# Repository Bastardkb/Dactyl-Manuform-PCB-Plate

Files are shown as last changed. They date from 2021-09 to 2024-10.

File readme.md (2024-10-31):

# Dactyl Manuform Mini PCB - plate

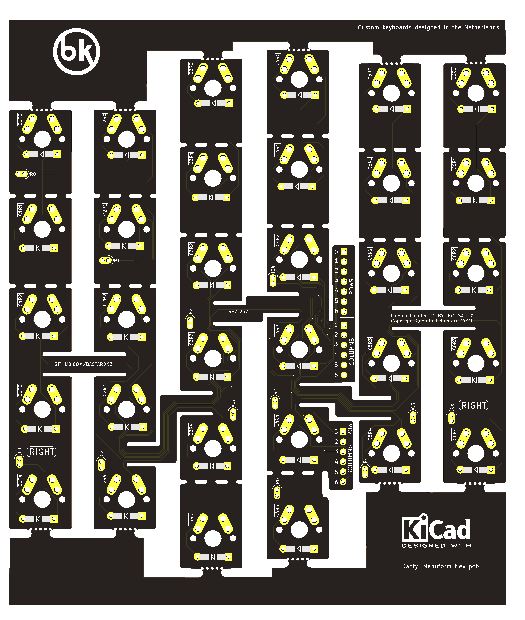
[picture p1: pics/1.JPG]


Flexible PCB made for the Dactyl Manuform Mini - up to 6x6 and breakable down to 5x3.

This repository contains all files necessary to order a PCB.

If you want to modify the design files, the Kicad sources are included (you will need a 5.99 nightly version).
If you just want to order the PCBs, check out the Release section which contain the gerber files.

## How to order

Order with a 0.6mm PCB thickness

## License

Licensed under CC BY-NC-SA 4.0
Copyright Quentin Lebastard 2021

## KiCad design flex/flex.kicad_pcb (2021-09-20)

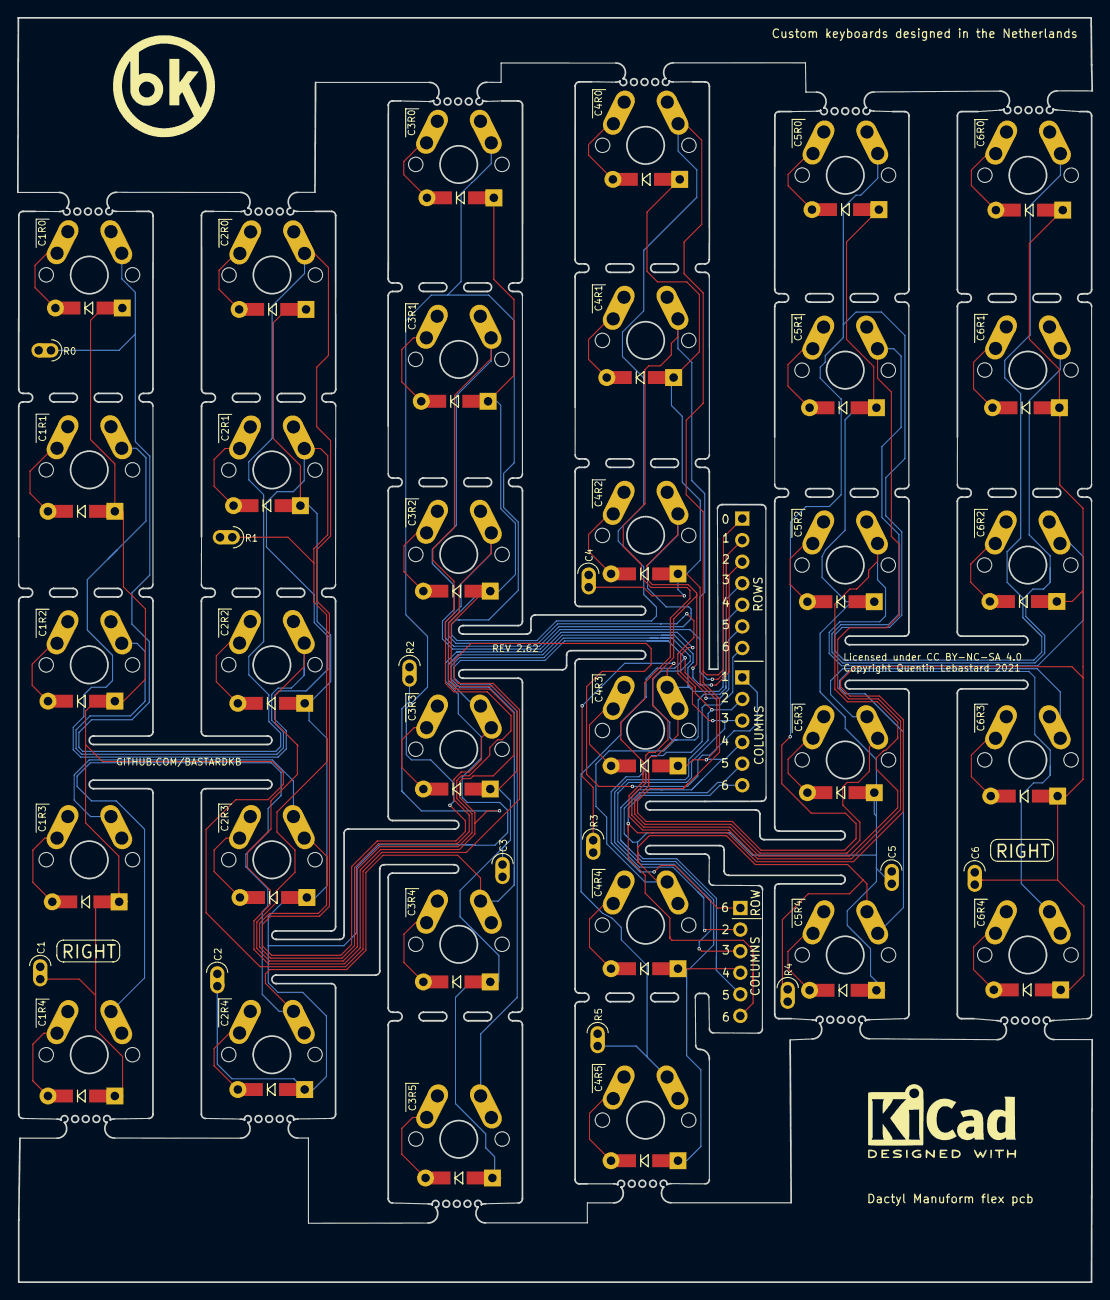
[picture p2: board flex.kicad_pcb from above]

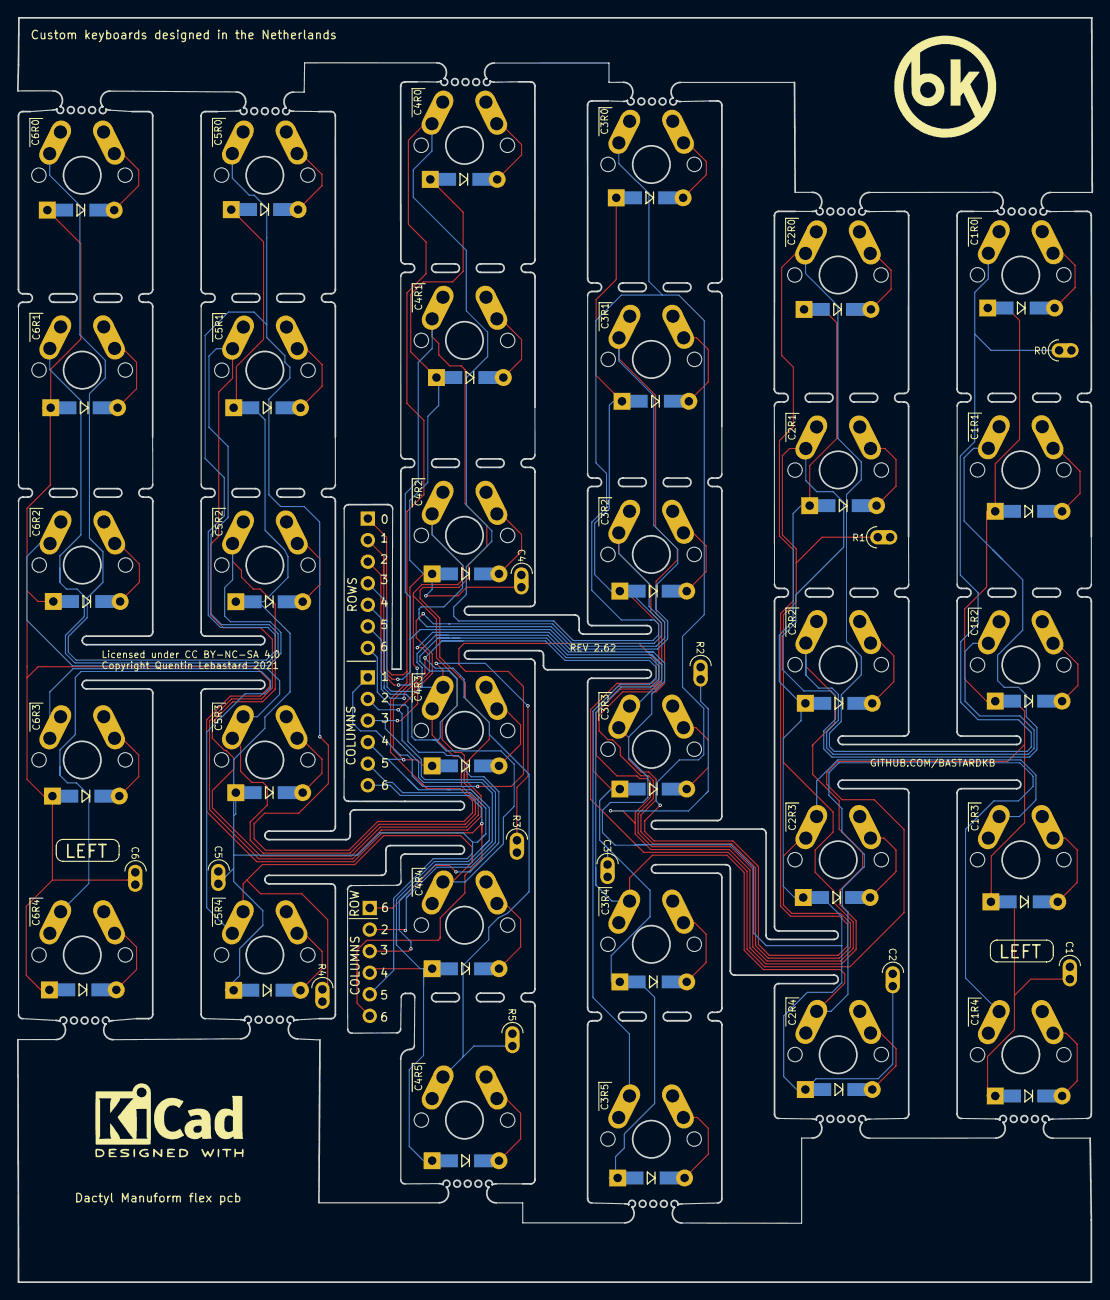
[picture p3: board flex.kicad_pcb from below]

Board: 2 copper layers, 126.5 x 148.9 mm, 79 parts (58 on the bottom side), 45 nets.

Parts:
D1, D2, D3, D4, D5, D6, D7, D8, D9, D10, D11, D12, D13, D14, D15, D16, D17, D18, D19, D20, D21, D22, D23, D24, D25, D26, D27, D28, D29, D30, D31, D32: D; Diode_TH_SOD123
J1, J14: Conn_01x06_Female; PinSocket_1x06_P2.54mm_Vertical
J2: Conn_01x07_Female; PinSocket_1x07_P2.54mm_Vertical
J3, J4, J5, J6, J7, J8, J9, J10, J11, J12, J13, J15: Conn_01x02_Female; SolderWire-0.15sqmm_1x01_D0.5mm_OD1.5mm
SW1, SW2, SW3, SW4, SW5, SW6, SW7, SW8, SW9, SW10, SW11, SW12, SW13, SW14, SW15, SW16, SW17, SW18, SW19, SW20, SW21, SW22, SW23, SW24, SW25, SW26, SW27, SW28, SW29, SW30, SW31, SW32: SW_Push; SW_MX_reversible

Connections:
unnamed: D1.2 (A), SW1.2
unnamed: D2.2 (A), SW2.2
unnamed: D3.2 (A), SW3.2
unnamed: D4.2 (A), SW4.2
unnamed: D5.2 (A), SW5.2
unnamed: D6.2 (A), SW6.2
unnamed: D7.2 (A), SW7.2
unnamed: D8.2 (A), SW8.2
unnamed: D9.2 (A), SW9.2
unnamed: D10.2 (A), SW10.2
unnamed: D11.2 (A), SW11.2
unnamed: D12.2 (A), SW12.2
unnamed: D13.2 (A), SW13.2
unnamed: D14.2 (A), SW14.2
unnamed: D15.2 (A), SW15.2
unnamed: D16.2 (A), SW16.2
unnamed: D17.2 (A), SW17.2
unnamed: D18.2 (A), SW18.2
unnamed: D19.2 (A), SW19.2
unnamed: D20.2 (A), SW20.2
unnamed: D21.2 (A), SW21.2
unnamed: D22.2 (A), SW22.2
unnamed: D23.2 (A), SW23.2
unnamed: D24.2 (A), SW24.2
unnamed: D25.2 (A), SW25.2
unnamed: D26.2 (A), SW26.2
unnamed: D27.2 (A), SW27.2
unnamed: D28.2 (A), SW28.2
unnamed: D29.2 (A), SW29.2
unnamed: D30.2 (A), SW30.2
unnamed: D31.2 (A), SW31.2
unnamed: D32.2 (A), SW32.2
col1: D1.1 (K), D2.1 (K), D3.1 (K), D4.1 (K), D27.1 (K), J9.1, J14.1
col2: D5.1 (K), D6.1 (K), D7.1 (K), D8.1 (K), D28.1 (K), J1.2, J10.1, J14.2
col3: D9.1 (K), D10.1 (K), D11.1 (K), D12.1 (K), D13.1 (K), D29.1 (K), J1.3, J11.1, J14.3
col4: D14.1 (K), D15.1 (K), D16.1 (K), D17.1 (K), D18.1 (K), D30.1 (K), J1.4, J12.1, J14.4
col5: D19.1 (K), D20.1 (K), D21.1 (K), D22.1 (K), D31.1 (K), J1.5, J13.1, J14.5
col6: D23.1 (K), D24.1 (K), D25.1 (K), D26.1 (K), D32.1 (K), J1.6, J14.6, J15.1
row0: J2.1, J3.1, SW27.1, SW28.1, SW29.1, SW30.1, SW31.1, SW32.1
row1: J2.2, J4.1, SW1.1, SW5.1, SW9.1, SW14.1, SW19.1, SW23.1
row2: J2.3, J5.1, SW2.1, SW6.1, SW10.1, SW15.1, SW20.1, SW24.1
row3: J2.4, J6.1, SW3.1, SW7.1, SW11.1, SW16.1, SW21.1, SW25.1
row4: J2.5, J7.1, SW4.1, SW8.1, SW12.1, SW17.1, SW22.1, SW26.1
row5: J2.6, J8.1, SW13.1, SW18.1
row6: J1.1, J2.7

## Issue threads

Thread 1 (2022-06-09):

What vendor have you used to manufacture this PCB?

efenderbosch, 2022-06-09:
I'm trying JLCPCB and they are having all sorts of issues understanding the gerber files. I've separated them in to two separate zips, flex_B and flex_F, but I think the fact that one is mirrored is really confusing them. Should I try to use Kicad to "unmirror" those? Thanks.

bstiq, 2022-06-09:
Hi,

We and others ordered them with JLC, so they can definetly manufacture them.
The B and F stand for Back and Front layers.

Did you grab the gerber from the release section ? Do you have maybe screenshots of the conversation with JLC ?

efenderbosch, 2022-06-09:
I did grab them from the release section. I created 2 zip from the contents:
- flex-B_*.gbr + flex-Edge_Cuts.gbr + flex-PTH.drl
- flex-H_*.gbr + flex-Edge_Cuts.gbr + flex-PTH.drl

Email conversation:
>Hi Sir or madam,
 Well got your order with many thanks~
 Sorry to bother you, but there is an issue that we want to confirm with you before proceeding.
 There is no bottom solder mask layer, is that normal? If it is normal, there are 2 option for reference. There is no bare copper available.（if it is wrong, we will help you activate the replace file button that you can fix and reupload）.
 A : We cover it all with tin.—(can solder things)
 B: we cover it all with solder mask ink.—(can’t solder anything)
 Your early reply will be highly appreciated!
 Thank you so much!

My reply:
> The zip files both have a mask.gbr, so I'm a little confused. One is designed to be printed and used "upside down" so they can both use the same board outline. flex_F is right side up (layers are in regular order) and flex_B is upside down (layers are in reverse order).

I also attached a picture of the final boards.

Their reply:
> Dear Customer,
 Sorry that the image cannot help to resolve this issue since we cannot see the bottom copper layer per the photo.
 As like below image shown, there is no bottom copper, bottom solder mask file.
 Could you please kindly advise?
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

efenderbosch, 2022-06-09:
I actually did that first then canceled that order because they couldn't figure it out. They were going to print everything together on the same PCB from what i could tell. Unless I'm the one with the misunderstanding.

>You need to pay additional 21.26 for your order. 2.62_Y2【4567235A_Y2】
 Reason:
 1.The order info shows that there is only one design , but actually, there are 6 different designs in your file, so there will be an extra cost for it if you want to make it as show in your file.Please kindly choose the correct designs when you place your order next time.
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

efenderbosch, 2022-06-10:
Ok, I think I'll try to resubmit the entire zip. Is there anything here that needs to be changed?

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

bstiq, 2022-06-10:
Hi,

You may want to check `yes` for `remove order number`. Otherwise looks good to me !

Regards,

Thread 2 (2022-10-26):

Different positions of switches

ashton, 2022-10-26:
Hi @bstiq, first of all I'm huge fan of your work! Not sure if this is an issue but it's the only place that I can reach you, so sorry in advance if this is misplaced.

I have done a dactyl manuform mini based on your [personal repo](https://github.com/bstiq/dactyl-manuform-mini-keyboard), and it is awesome! I tried to organize a little bit the mess of wires due to handwiring, and I tought that this PCB would be a great way to do it. You say in the description that is compatible with dactyl manuform mini, in fact, if I'm not mistaken the thumb cluster pcb only works with mini. But after printing it and trying to build it, looks like that some of the switch positions are misplaced with the switch holes in the case, the stagger in the pinky and ring columns seems to be greater in the case than in the PCB and the spacing between the columns is different too. I don't have a lot of knowledge in Kicad but is there a way of fixing this? Is there a way of generate a pcb that would work well with my case?

Sorry for asking this here, and thanks in advance for the help!

bstiq, 2022-10-28:
Hi,

Thanks !
The thumb cluster is only compatible with certain types of dactyls.
It's compatible with all my keyboards, and _should be_ with the og dactyl manuform mini:
https://github.com/l4u/dactyl-manuform-mini-keyboard

You can either use a different case model, or modify the PCB like you mentioned.
There's no way to generate it, you will need to change the edge cuts and position of the switches so it fits better (I recommend 3d printing tests), then handwiring everything.

It's quite a big project and I wouldn't recommend it if you don't have a lot of experience with PCB design.

If you want to go ahead or have questions about that, a better place to chat is on the bastardkb discord.
bastardkb.com/discord

Regards,

Closed 2022-10-28.

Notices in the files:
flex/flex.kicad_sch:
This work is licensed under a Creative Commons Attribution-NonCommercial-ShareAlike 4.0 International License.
